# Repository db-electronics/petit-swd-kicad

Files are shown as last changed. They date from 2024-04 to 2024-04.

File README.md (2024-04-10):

# Petit SWD
Petit SWD is an ARM JTAG adapter which reduces the 2x10 100mil connector to a 1x4 100mil connector better suited for SWD debugging. It also has a type B USB input to provide power to the target board from either VBUS 5V or 3.3V from an onboard voltage regulator. This is selectable via pin header.

# Support Open Source
If you're going to use my free projects please consider sponsoring my work. Thanks!

- [Github Sponsor](https://github.com/sponsors/db-electronics)
- [Pateron](https://patreon.com/dbelectronics)

## Changelog
- [v1.0](https://github.com/db-electronics/petit-swd-kicad/releases/tag/v1.0)
  - initial release

# Copyright and Disclaimer
Copyright: René Richard

This documentation describes Open Hardware and is licensed under the
CERN OHL v. 1.2.

You may redistribute and modify this documentation under the terms of the
CERN OHL v.1.2. (http://ohwr.org/cernohl). This documentation is distributed
WITHOUT ANY EXPRESS OR IMPLIED WARRANTY, INCLUDING OF
MERCHANTABILITY, SATISFACTORY QUALITY AND FITNESS FOR A
PARTICULAR PURPOSE. Please see the CERN OHL v.1.2 for applicable
conditions

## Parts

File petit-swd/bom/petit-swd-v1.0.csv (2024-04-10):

Item | Qty | Reference(s) | Value | LibPart | Footprint | Description | Supplier | Supplier Number
1 | 2 | C101, C102 | 10uF/25V | C_0805 | 0805 | CAP CER 10UF 25V X5R 0805 | www.digikey.ca | 1276-2891-1-ND
2 | 1 | CON101 | 302-S201 | JTAG-2X10-HDR | HDR2X10-JTAG-SHROUD | CONN HEADER VERT 20POS 2.54MM | www.digikey.ca | ED10524-ND
3 | 1 | CON102 | 61300411121 | SWD_HDR1X4 | HDR1X4 | CONN HEADER VERT 4POS 2.54MM | www.digikey.ca | 732-5317-ND
4 | 1 | CON103 | PPTC041LGBN-RC | SWD_RCP1X4_RA | RCP1X4_RA | CONN HDR 4POS 0.1 TIN PCB R/A | www.digikey.ca | S5440-ND
5 | 1 | CON104 | USB-B1HSB6 | USB-B1HSB6 | USB-B1HSxx | CONN USB TYPE B R/A BLACK | www.digikey.ca | ED2983-ND
6 | 1 | CON105 | 61300311121 | HDR1X3 | HDR1X3 | CONN HEADER VERT 3POS 2.54MM | www.digikey.ca | 732-5316-ND
7 | 1 | CON106 | 61300211121 | HDR1X2 | HDR1X2 | CONN HEADER VERT 2POS 2.54MM | www.digikey.ca | 732-5315-ND
8 | 1 | U101 | AZ1117CH-3.3TRG1 | AZ1117CH-3.3TRG1_1 | SOT-223 | IC REG LINEAR 3.3V 800MA SOT223 | www.digikey.ca | AZ1117CH-3.3TRG1DICT-ND

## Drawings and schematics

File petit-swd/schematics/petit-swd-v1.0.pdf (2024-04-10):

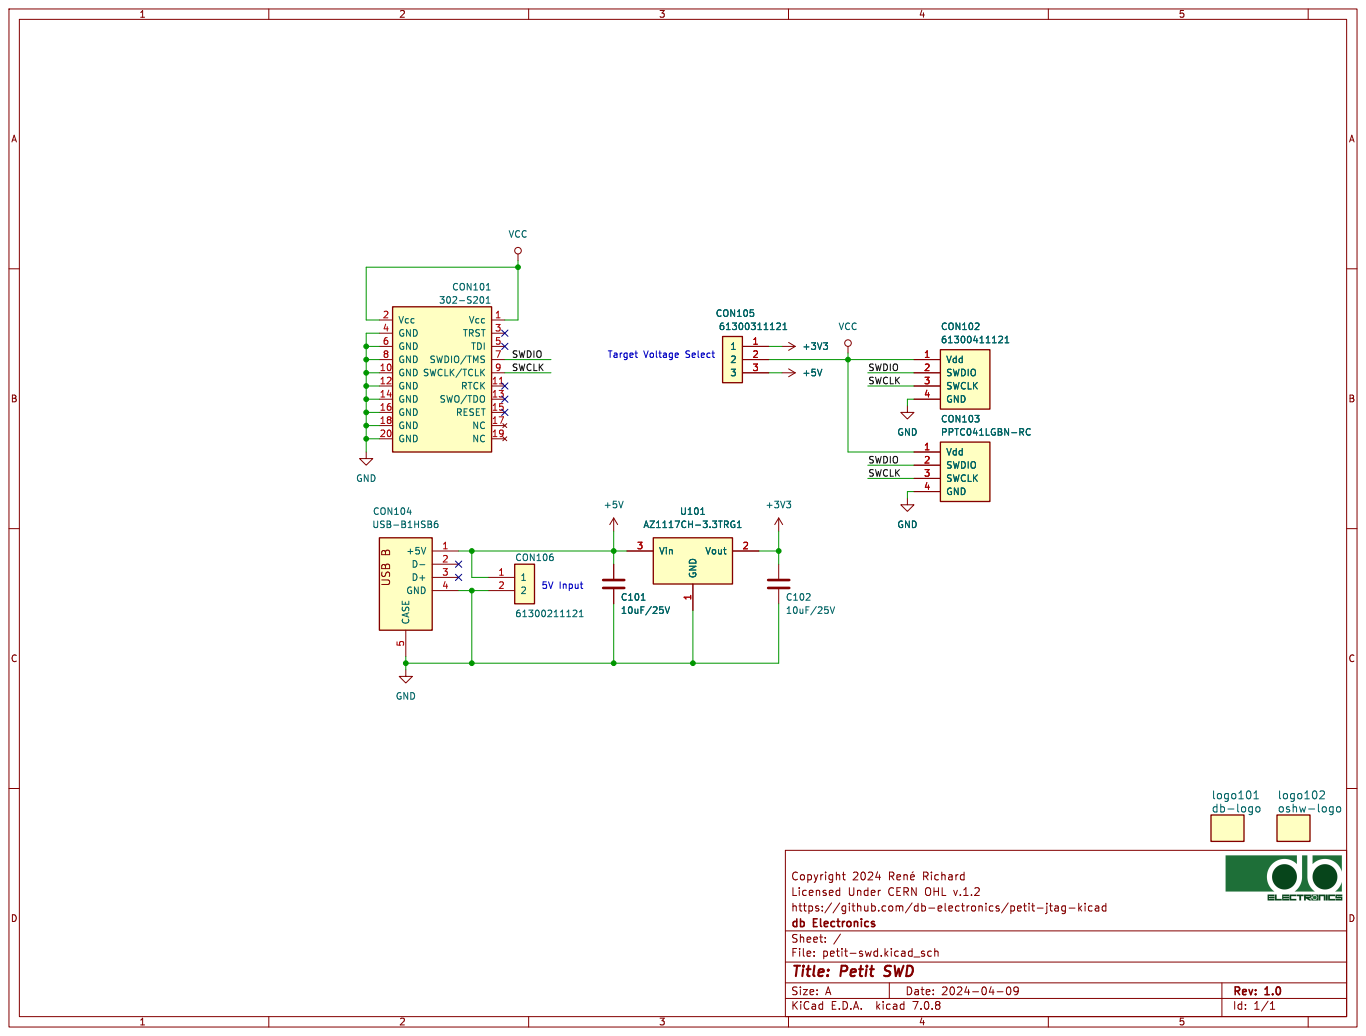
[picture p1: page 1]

Licensed | Under CERN OHL v.1.2 Copyright 2024 | þÿRené Richard

https://github.com/db-electronics/petit-jtag-kicad

E.D.A. kicad 7.0.8 Size: A Rev: 1.0 | D Date: 2024-04-09 KiCad

Id: 1/1 Title: Petit SWD

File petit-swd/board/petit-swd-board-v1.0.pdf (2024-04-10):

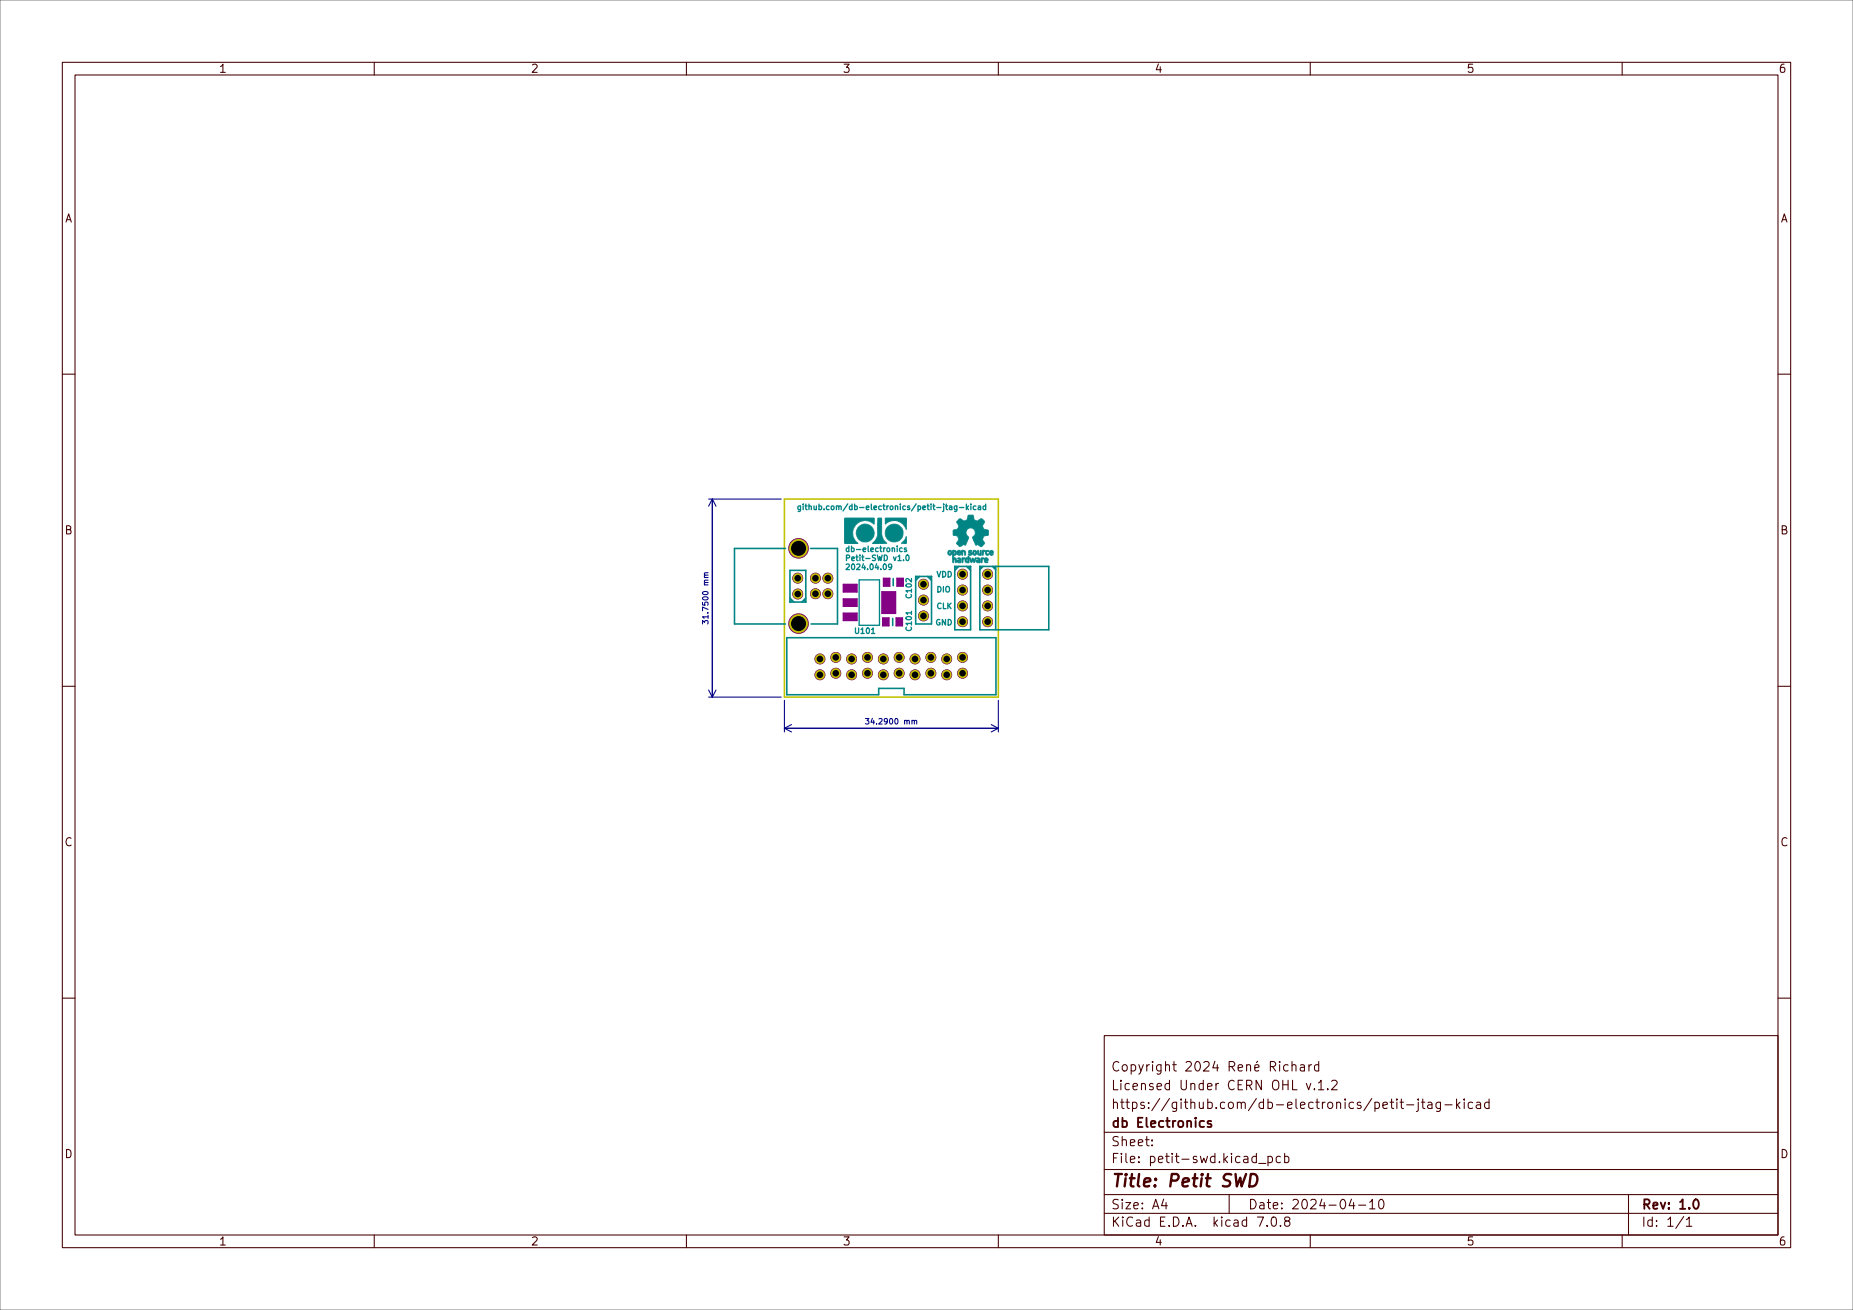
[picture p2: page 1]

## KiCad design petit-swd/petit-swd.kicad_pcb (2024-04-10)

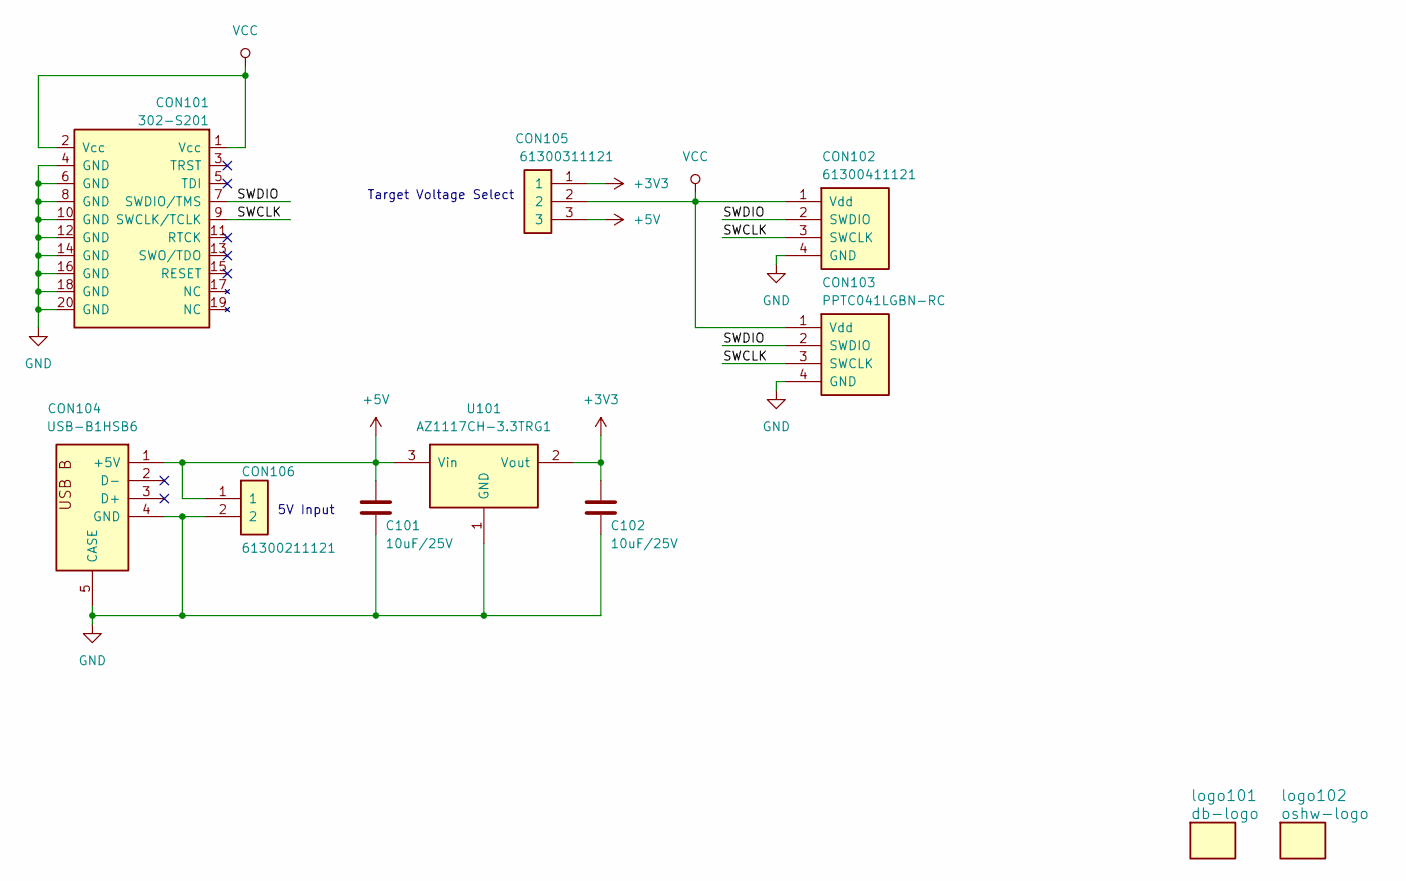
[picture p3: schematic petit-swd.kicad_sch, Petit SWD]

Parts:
C101, C102: 10uF/25V; 0805
CON101: 302-S201; HDR2X10-JTAG-SHROUD
CON102: 61300411121; HDR1X4
CON103: PPTC041LGBN-RC; RCP1X4_RA
CON104: USB-B1HSB6; USB-B1HSxx
CON105: 61300311121; HDR1X3
CON106: 61300211121; HDR1X2
U101: AZ1117CH-3.3TRG1; SOT-223
logo101: db-logo; db-logo_10mm
logo102: oshw-logo; oshw-logo_7.5mm

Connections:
+3V3: C102.1, CON105.1, U101.2 (Vout)
+5V: C101.1, CON104.1 (+5V), CON105.3, CON106.1, U101.3 (Vin)
/SWCLK: CON101.9 (SWCLK/TCLK), CON102.3 (SWCLK), CON103.3 (SWCLK)
/SWDIO: CON101.7 (SWDIO/TMS), CON102.2 (SWDIO), CON103.2 (SWDIO)
GND: C101.2, C102.2, CON101.4 (GND), CON101.6 (GND), CON101.8 (GND), CON101.10 (GND), CON101.12 (GND), CON101.14 (GND), CON101.16 (GND), CON101.18 (GND), CON101.20 (GND), CON102.4 (GND), CON103.4 (GND), CON104.4 (GND), CON104.5 (CASE), CON106.2, U101.1 (GND)
VCC: CON101.1 (Vcc), CON101.2 (Vcc), CON102.1 (Vdd), CON103.1 (Vdd), CON105.2

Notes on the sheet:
Target Voltage Select
5V Input

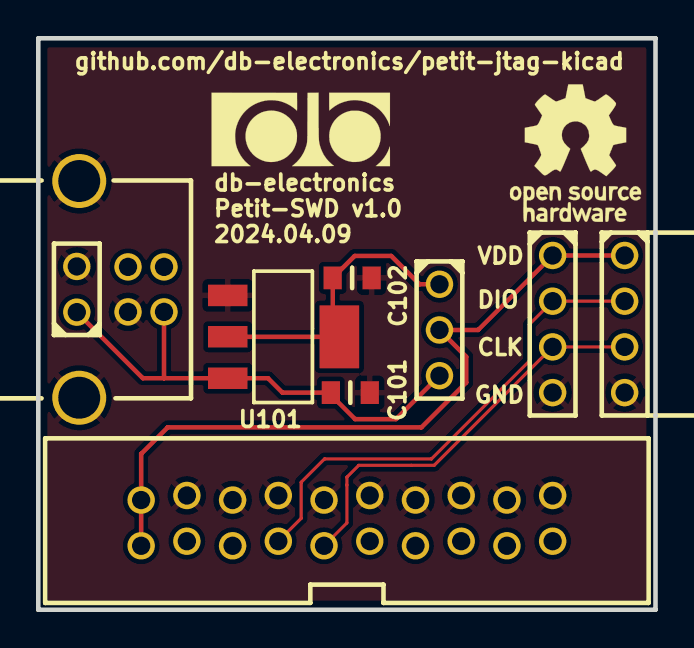
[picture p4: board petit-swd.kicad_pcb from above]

Board: 2 copper layers, 34.3 x 31.8 mm, 11 parts (0 on the bottom side), 6 nets.

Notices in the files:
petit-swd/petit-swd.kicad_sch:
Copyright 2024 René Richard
